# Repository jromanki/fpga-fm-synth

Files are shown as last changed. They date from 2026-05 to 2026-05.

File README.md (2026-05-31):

# fpga-fm-synth
Poniżej przedstawiono strukturę najważniejszych katalogów i plików projektu wraz z krótkim opisem ich zawartości.

 - `synth-tangnano20k` - Katalog zawierający kompletną logikę syntezatora zaimplementowaną w języku Verilog. W podkatalogu `src` znajdują się wydzielone moduły odpowiedzialne za syntezę polifoniczną, generację sygnałów nośnych i modulujących (DDS), a także warstwę sprzętową komunikacji (SPI, I2S).
 - `control-blackpill` - Projekt przygotowany w środowisku STM32CubeMX. Zawiera kod odpowiedzialny za odbieranie i dekodowanie komunikatów z klawiatury MIDI za pośrednictwem portu UART, algorytm dynamicznej alokacji głosów oraz procedury sterujące przesyłaniem danych konfiguracyjnych do układu FPGA.
 - `hardware` - Zawiera schemat sprzętowy wykonany w programie KiCad oraz użyte biblioteki komponentów jako submoduły git.
 - `scripts` - Zestaw skryptów pomocniczych w języku Python służących m.in. do generacji tablic LUT, konwersji parametrów MIDI na wartości sterujące dla układu FPGA oraz wyznaczania optymalnych częstotliwości PLL układu.

## Struktura repozytorium - część STM32
```
control-blackpill
|-- build                   - katalog plikow wynikowych kompilacji
|-- Core                    - kod zrodlowy aplikacji MCU
|   |-- Inc
|   |   `-- midi.h          - definicje struktur i protokolu MIDI
|   `-- Src
|       |-- freertos.c      - konfiguracja FreeRTOS, definicja taskow
|       |                   (SPI + MIDI + LED sync)
|       |-- main.c          - punkt inicjalizacji systemu
|       |-- midi.c          - dekodowanie komunikatow MIDI,
|       |                   przydzial glosow,
|       |                   konwersja danych MIDI->FPGA,
|       |                   sterowanie modulacja i glosnoscia
|       `-- usart.c         - UART MIDI RX -> kolejka do dekodowania
|-- Drivers                 - biblioteki HAL/CMSIS STM32
|-- freertos-blink.ioc      - konfiguracja projektu STM32CubeMX
`-- Makefile                - skrypt budowania projektu MCU
```

## Struktura repozytorium - część FPGA

```
synth-tangnano20k
|-- build               - katalog na wyniki syntezy i place&route
|-- mk.sh               - skrypt automatyzujacy proces budowania
|-- pinout.cst          - plik przypisania pinow ukladu FPGA
|-- src                 - kod zrodlowy logiki FPGA w jezyku Verilog
|   |-- dds             - moduly implementacji pojedynczego glosu
|   |                   (DDS, LUT, modulacja)
|   |-- i2s.v           - interfejs transmisji audio I2S
|   |-- mixer.v         - sumowanie sygnalow wielu glosow
|   |-- pll.v           - konfiguracja i uzycie petli PLL
|   |-- spi             - moduly obslugi komunikacji SPI
|   |-- spi_parser.v    - dekodowanie ramek SPI na komendy sterujace
|   `-- top.v           - glowny modul systemu FPGA
`-- tb                  - testbenche symulacyjne
    |-- i2s             - symulacja i weryfikacja interfejsu I2S
    |-- spi             - symulacja interfejsu SPI
    `-- sq_gen.v        - generator przebiegow prostokatnych (test)
```

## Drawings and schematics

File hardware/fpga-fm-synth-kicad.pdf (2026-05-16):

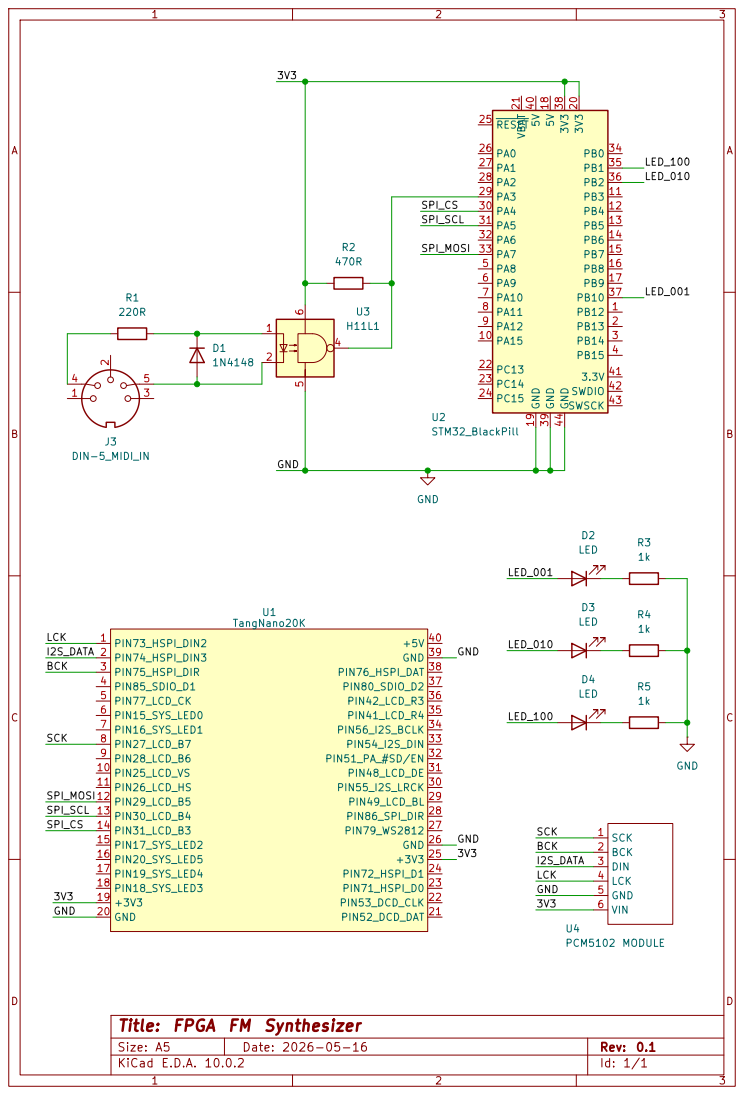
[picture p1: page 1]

Title: FPGA FM Synthesizer

Size: A5 | Rev: 0.1
KiCad E.D.A. 10.0.2 | Id: 1/1

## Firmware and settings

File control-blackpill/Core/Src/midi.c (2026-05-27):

#include <math.h>
#include <stdbool.h>

#include "main.h"
#include "midi.h"
#include "cmsis_os.h"

enum msg_state {
    STATE_WAITING_STATUS,
    STATE_WAITING_DATA_1,
    STATE_WAITING_DATA_2
};
 
typedef struct {
    uint8_t note_value;
    uint8_t note_age;
    bool active;
} voice_t;
 

uint32_t midi_to_phase_inc_arr[] = { 709, 752, 796, 844, 894, 947, 1003, 1063, 1126, 1193, 1264, 1339, 1419, 1503, 1593, 1687, 1788, 1894, 2006, 2126, 2252, 2386, 2528, 2678, 2838, 3006, 3185, 3374, 3575, 3788, 4013, 4252, 4504, 4772, 5056, 5357, 5675, 6013, 6370, 6749, 7150, 7575, 8026, 8503, 9009, 9544, 10112, 10713, 11350, 12025, 12740, 13498, 14300, 15151, 16052, 17006, 18017, 19089, 20224, 21426, 22700, 24050, 25480, 26996, 28601, 30301, 32103, 34012, 36035, 38177, 40448, 42853, 45401, 48101, 50961, 53991, 57202, 60603, 64207, 68025, 72069, 76355, 80895, 85706, 90802, 96201, 101922, 107982, 114403, 121206, 128413, 136049, 144139, 152710, 161791, 171411, 181604, 192402, 203843, 215964, 228806, 242412, 256826, 272098, 288278, 305420, 323581, 342822, 363208, 384805, 407687, 431929, 457613, 484824, 513653, 544196, 576556, 610840, 647162, 685644, 726415, 769610, 815373, 863858, 915226, 969648, 1027306, 1088393 };
uint16_t exp_volume_arr[] = { 0, 42, 57, 72, 87, 103, 119, 137, 157, 177, 199, 222, 247, 273, 301, 331, 362, 395, 431, 468, 507, 549, 593, 640, 689, 740, 795, 852, 912, 975, 1041, 1111, 1184, 1261, 1341, 1425, 1513, 1606, 1702, 1803, 1909, 2019, 2134, 2254, 2380, 2511, 2648, 2790, 2939, 3094, 3255, 3423, 3598, 3780, 3969, 4166, 4371, 4584, 4806, 5036, 5274, 5523, 5780, 6048, 6325, 6613, 6912, 7222, 7543, 7876, 8221, 8579, 8949, 9333, 9731, 10142, 10568, 11009, 11466, 11938, 12426, 12931, 13454, 13994, 14553, 15130, 15726, 16343, 16979, 17637, 18317, 19018, 19742, 20490, 21262, 22059, 22881, 23729, 24604, 25507, 26438, 27398, 28387, 29408, 30460, 31544, 32662, 33813, 34999, 36222, 37481, 38778, 40113, 41489, 42905, 44363, 45863, 47408, 48998, 50634, 52318, 54050, 55832, 57665, 59551, 61490, 63484, 65535 };
voice_t voices[NUM_OF_VOICES];

static volatile enum msg_state current_state = STATE_WAITING_STATUS;
static volatile uint8_t msg_type;
static volatile uint8_t first_data_msg;
static volatile uint8_t last_freq_mult;
extern osMessageQueueId_t to_send_queueHandle;

/* ======================== STATIC FUNCTIONS DECLARATIONS ======================== */

static uint8_t assemble_message(
    fpga_msg_t* fpga_msg,
    uint8_t msg_type,
    uint8_t data1,
    uint8_t data2);


static uint8_t assign_voice_note_on(uint8_t midi_note);

/**
 * @brief   This function decides which voice should be turned off on
 *          MIDI OFF message
 * 
 * @param midi_note     MIDI note value
 * @return int8_t       Returns oscillator ID if found voice playing requested
 *                      note, if not returns -1 (note got stolen before)
 */
static int8_t assign_voice_note_off(uint8_t midi_note);

static uint8_t get_channel(uint8_t rcv_msg);
static uint8_t get_msg_kind(uint8_t rcv_msg);
static uint32_t map_mod_freq_mult(uint8_t data);
static uint8_t is_my_note_on_msg(uint8_t rcv_msg);
static uint8_t is_my_note_off_msg(uint8_t rcv_msg);
static uint8_t is_my_cc_chg_msg(uint8_t rcv_msg);
void display_freq_mult(uint8_t freq_mult);

/* ======================== GLOBAL FUNCTIONS DEFINITIONS ======================== */

void display_freq_mult(uint8_t freq_mult)
{
    uint16_t mask = 0;
    uint8_t program = freq_mult + 1;

    if (program & 0x01) {
        mask |= GPIO_PIN_10;
    }
    if (program & 0x02) {
        mask |= GPIO_PIN_2;
    }
    if (program & 0x04) {
        mask |= GPIO_PIN_1;
    }

    HAL_GPIO_WritePin(GPIOB,
        GPIO_PIN_10 | GPIO_PIN_2 | GPIO_PIN_1,
        GPIO_PIN_RESET);

    HAL_GPIO_WritePin(GPIOB, mask, GPIO_PIN_SET);
}

void process_midi(uint8_t rcv_msg)
{
    if (rcv_msg >= 0xF8) return;

    if (HAS_STATUS_BIT(rcv_msg)) {
        msg_type = get_msg_kind(rcv_msg);

        if (is_my_note_on_msg(rcv_msg)) {
            /* is a note on message */
            current_state = STATE_WAITING_DATA_1;
        }
        else if (is_my_note_off_msg(rcv_msg)) {
            /* is a note off message */
            current_state = STATE_WAITING_DATA_1;
        }
        else if (is_my_cc_chg_msg(rcv_msg)) {
            /* is a control change message */
            current_state = STATE_WAITING_DATA_1;
        }
        else {
            current_state = STATE_WAITING_STATUS;
        }
    }
    else {
        uint8_t data = rcv_msg; 

        switch (current_state) {
            case STATE_WAITING_DATA_1:
                /* is a first data message of supported status message */
                first_data_msg = data;

                if ((msg_type == NOTE_ON_MSG) || (msg_type == NOTE_OFF_MSG)) {
                    fpga_msg_t fpga_msg;

                    /* translate message for spi */
                    if (assemble_message(&fpga_msg, msg_type, data, 0)) {
                        break;
                    }

                    /* put this message on a queue to be sent over spi */
                    osMessageQueuePut(to_send_queueHandle, &fpga_msg, 0, 10);
                }
                
                current_state = STATE_WAITING_DATA_2;
                break;

            case STATE_WAITING_DATA_2:
                /* is a 2nd data message of supported status message */
                if (msg_type == CTRL_CHG_MSG) {
                    fpga_msg_t fpga_msg;

                    /* translate message for spi */
                    if (assemble_message(&fpga_msg, msg_type, first_data_msg, data)){
                        break;
                    }

                    /* put this message on a queue to be sent over spi */
                    osMessageQueuePut(to_send_queueHandle, &fpga_msg, 0, 10);
                };

                break;
                
            default:
                break;
        }
    }
}

void init_voices() {
    /* init to very old value */
    for (int i=0; i<NUM_OF_VOICES; i++) {
        voices[i].active = false;
    }
}

/* ======================== STATIC FUNCTIONS DEFINITIONS ======================== */
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

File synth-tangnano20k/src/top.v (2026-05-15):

module top #(
    /* Num of click cycles per L/R toggle. */
    parameter integer DIV = 100,
    /* Num of voices (also needs changes in mixer module) */
    parameter integer VOICE_NUM = 10
) (
    input       ext_clk,
    input       btn,
    input       btn2,

    input       scl,
	input       mosi,
	input       cs,

    output      sck,
    output      bck,
    output      lrck,
    output      dout,

    output      [5:0] led,

    output      test_1
);

    /* Main regs/wires */
    wire sys_clk;
    wire [31:0] final_sample;
    reg [31:0] data_l;
    reg [31:0] data_r;
    reg [15:0] master_volume_mult;
    reg sync_tick_last;
    reg dac_ready;
    reg [21:0] led_timer [5:0];
    reg led_on [5:0];

    reg [31:0] sys_spi_data;
    reg [4:0] sys_spi_target_osc;
    reg [2:0] sys_spi_msg_type;
    wire sys_spi_ready;
    reg note_msg_ready;

    /* SPI wires/regs */
    wire sys_lrck;
    wire sys_dout;
    wire sys_sync_tick;
    wire sys_bck;

    /* Per voice regs */
    reg [2:0]   osc_mod_freq_mult_setting;
    reg [7:0]   osc_mod_depth;
    reg [31:0]  sys_phase_inc [VOICE_NUM-1:0];
    reg [15:0]  osc_vol_mult [VOICE_NUM-1:0];
    wire [31:0] sample [VOICE_NUM-1:0];

    /* for loops for code clarity */
    integer i;

    /* simple power on reset */
    reg [15:0] por_counter = 0;
    wire auto_rst = !por_counter[15];
    always @(posedge sys_clk) begin
        if (auto_rst) begin
            por_counter <= por_counter + 1;
        end
    end

    always @ (posedge sys_clk) begin

        /* make dac_ready detect rising edge of sync_tick */
        sync_tick_last <= sys_sync_tick;
        dac_ready <= (sys_sync_tick && !sync_tick_last);
        note_msg_ready <= sys_spi_ready;

        if (btn | auto_rst) begin
            sync_tick_last <= 0;
            dac_ready <= 0;
            
            osc_mod_freq_mult_setting <= 3'b000;
            osc_mod_depth <= 7'b0000000;
            master_volume_mult <= 16'hFFFF;

            /* clear led regs */
            for (i = 0; i < 6; i = i + 1) begin
                led_timer[i] <= 0;
                led_on[i] <= 0;
            end

            /* clear per-voice setting regs */
            for (i = 0; i < VOICE_NUM-1; i = i + 1) begin
                sys_phase_inc[i] <= 0;
                osc_vol_mult[i] <= 16'hFFFF;
            end

            
        end
        else begin
            if (note_msg_ready) begin
                /* If new spi message came */

                if (sys_spi_msg_type == 3'b001) begin
                    /* if note on message */
                    
                    /* assign phase incrementation to get correct freq */
                    sys_phase_inc[sys_spi_target_osc] <= sys_spi_data;

                    /* turn on the note sound output */
                    osc_vol_mult[sys_spi_target_osc] <= 16'hFFFF;

                    /* signalize with led */
                    if (sys_spi_target_osc < 6) begin
                        led_timer[sys_spi_target_osc] <= 22'h3FFFFF;
                        led_on[sys_spi_target_osc] <= 1;
                    end
                end

                if (sys_spi_msg_type == 3'b000) begin
                    /* note off message */

                    /* turn off the note sound output */
                    osc_vol_mult[sys_spi_target_osc] <= 16'h0000;

                    /* signalize with led */
                    if (sys_spi_target_osc < 6) begin
                        led_timer[sys_spi_target_osc] <= 22'h3FFFFF;
                        led_on[sys_spi_target_osc] <= 1;
                    end
                end

                if (sys_spi_msg_type == 3'b111) begin
                    /* volume change message */
                    master_volume_mult <= sys_spi_data[15:0];
                    led_timer[0] <= 22'h3FFFFF;
                    led_on[0] <= 1;
                end

                if (sys_spi_msg_type == 3'b010) begin
                    /* change modulation depth message */
                    osc_mod_depth <= sys_spi_data[6:0];
                    led_timer[0] <= 22'h3FFFFF;
                    led_on[0] <= 1;
                end

                if (sys_spi_msg_type == 3'b011) begin
                    /* change modulation frequency multiplier depth message */
                    osc_mod_freq_mult_setting <= sys_spi_data[2:0];
                    led_timer[0] <= 22'h3FFFFF;
                    led_on[0] <= 1;
                end
            end
            else if (btn2) begin
                /* test mode */
                sys_phase_inc[1] <= 9544;
            end

            /* if both words have been transmitted dac_ready = 1
                for 1 sys_clk cycle */
            if (dac_ready) begin
                data_l <= final_sample;
                data_r <= final_sample;
            end

            /* blink leds for a short time if led_on was set */ 
            for (i = 0; i < 6; i = i + 1) begin
                if (led_timer[i] > 0) begin
                    led_timer[i] <= led_timer[i] - 1;
                    led_on[i] <= 1;
                end
                else begin
                    led_on[i] <= 0;
                end
            end

        end
    end


    /* PLL 49.5 Mhz */
    pll pll (
        .clock_in(ext_clk),
        .clock_out(sys_clk),
        .locked()
    );

    spi_parser spi_parser (
        .clk(sys_clk),
        .rst(btn | auto_rst),
        .scl(scl),
        .mosi(mosi),
        .cs(cs),
        .data_ready(sys_spi_ready),
        .data_out(sys_spi_data),
        .target_osc_out(sys_spi_target_osc),
        .msg_type_out(sys_spi_msg_type)
    );


    /* Voice instances */

    voice voice0 (
        .clk(sys_clk),
        .rst(btn),
        .tick(sys_sync_tick),
        .phase_inc(sys_phase_inc[0]),
        .mod_freq_mult_setting(osc_mod_freq_mult_setting),
        .mod_depth(osc_mod_depth),
        .volume_mult(osc_vol_mult[0]),
        .value(sample[0])
    );

    voice voice1 (
        .clk(sys_clk),
        .rst(btn),
        .tick(sys_sync_tick),
        .phase_inc(sys_phase_inc[1]),
        .mod_freq_mult_setting(osc_mod_freq_mult_setting),
        .mod_depth(osc_mod_depth),
        .volume_mult(osc_vol_mult[1]),
        .value(sample[1])
    );

    voice voice2 (
        .clk(sys_clk),
        .rst(btn),
        .tick(sys_sync_tick),
        .phase_inc(sys_phase_inc[2]),
        .mod_freq_mult_setting(osc_mod_freq_mult_setting),
        .mod_depth(osc_mod_depth),
        .volume_mult(osc_vol_mult[2]),
        .value(sample[2])
    );

    voice voice3 (
        .clk(sys_clk),
        .rst(btn),
        .tick(sys_sync_tick),
        .phase_inc(sys_phase_inc[3]),
        .mod_freq_mult_setting(osc_mod_freq_mult_setting),
        .mod_depth(osc_mod_depth),
        .volume_mult(osc_vol_mult[3]),
        .value(sample[3])
    );
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

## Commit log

2026-03-17 spi without dma task
2026-03-22 working uart interrupt on midi notes
2026-03-24 working sending phase incrementation over spi
2026-03-26 added chip select line on pin A4
2026-04-01 corrected frequencies in midi array
    [midi.c]
2026-04-15 bot notes sort of playing, mixer not working
    [top.v]
2026-04-17 restructured to a single repo
    [midi.csv]
2026-04-17 restructured to a single repo 2
    [midi.csv]
2026-04-23 created kicad hardware sketch, updated pinouts, added leds signalising current freq mult setting
2026-04-23 created kicad hardware sketch, updated pinouts, added leds signalising current freq mult setting 2
    [fpga-fm-synth-kicad.kicad_pcb, fpga-fm-synth-kicad.kicad_sch]
2026-05-16 improved kicad schematic
    [fpga-fm-synth-kicad.kicad_sch]
2026-05-19 Fixed mistakes found while writing the paper - fixed midi_to_phase_inc_arr and script generating it - matched FSM names to the ones in the paper
    [midi.c]
2026-05-29 cleaned repo
    [midi.csv]
